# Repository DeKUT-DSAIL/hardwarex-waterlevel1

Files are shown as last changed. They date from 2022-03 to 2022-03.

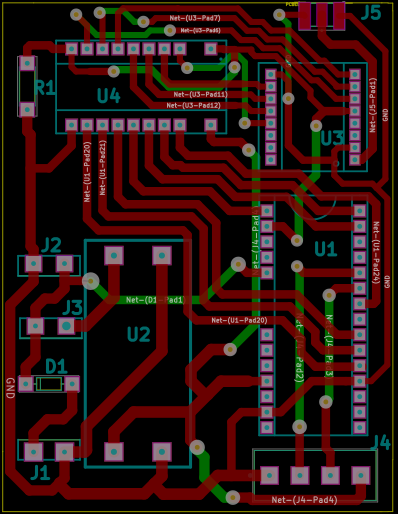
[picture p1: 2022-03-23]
arduino-waterlevel-hardware/design_pdfs/arduino_sytem-pcb.PNG

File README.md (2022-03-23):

## hardwarex-waterlevel1
### A Low Cost LoRa Based River Water Level Data Acquisition System (Design Files)
#### Contents
- Arduino Nano based stage monitoring system - Kicad design files (etching pdf available)
- Multitech mDot based stage monitoring system - Kicad design files (etching pdf available)
- Arduino Nano based stage monitoring system - Arduino IDE code (Firmware)
- TTN (The Things Network) payload formatter for the Multitech mDot based stage monitoring system (in JavaScript)

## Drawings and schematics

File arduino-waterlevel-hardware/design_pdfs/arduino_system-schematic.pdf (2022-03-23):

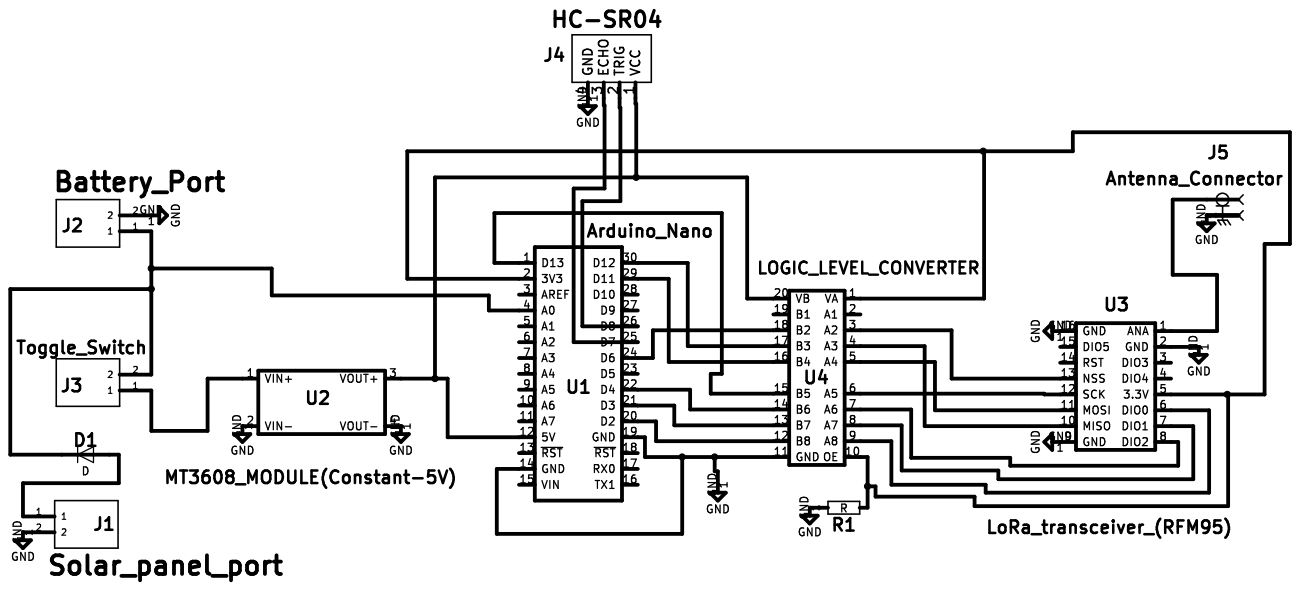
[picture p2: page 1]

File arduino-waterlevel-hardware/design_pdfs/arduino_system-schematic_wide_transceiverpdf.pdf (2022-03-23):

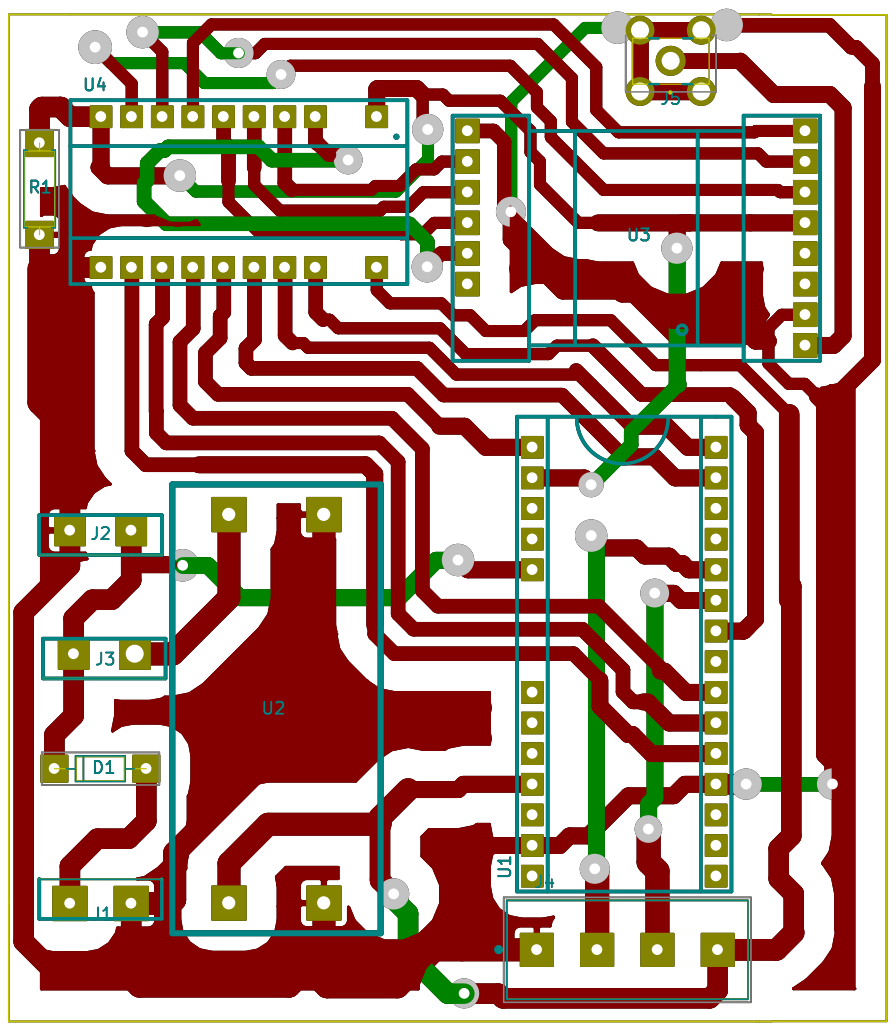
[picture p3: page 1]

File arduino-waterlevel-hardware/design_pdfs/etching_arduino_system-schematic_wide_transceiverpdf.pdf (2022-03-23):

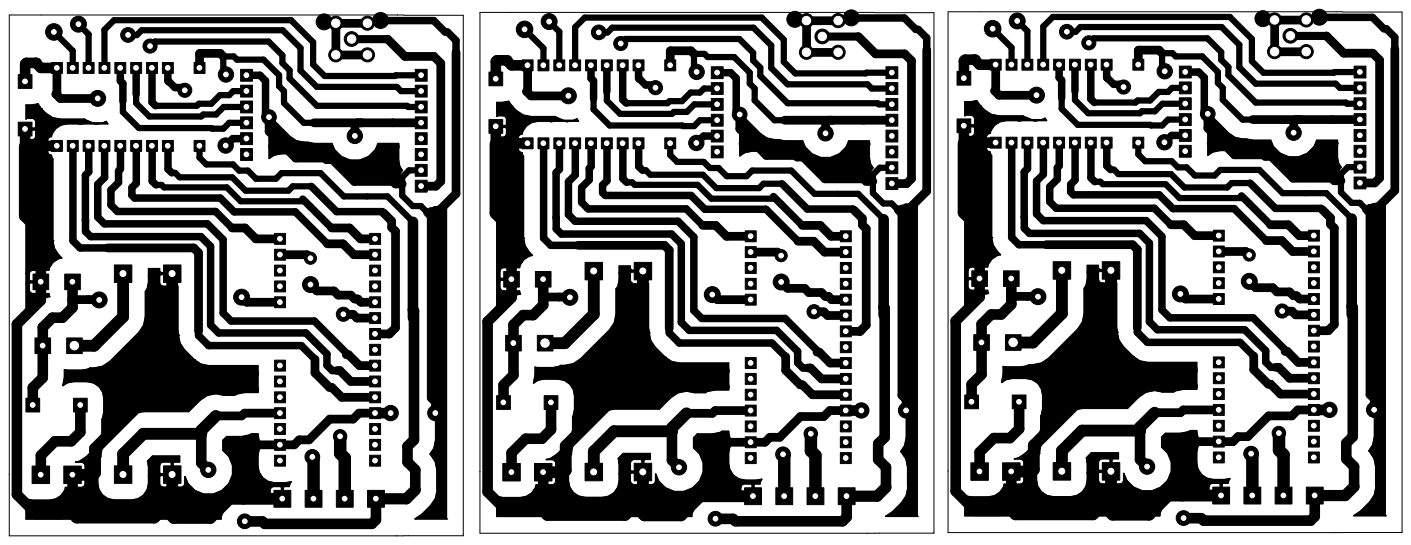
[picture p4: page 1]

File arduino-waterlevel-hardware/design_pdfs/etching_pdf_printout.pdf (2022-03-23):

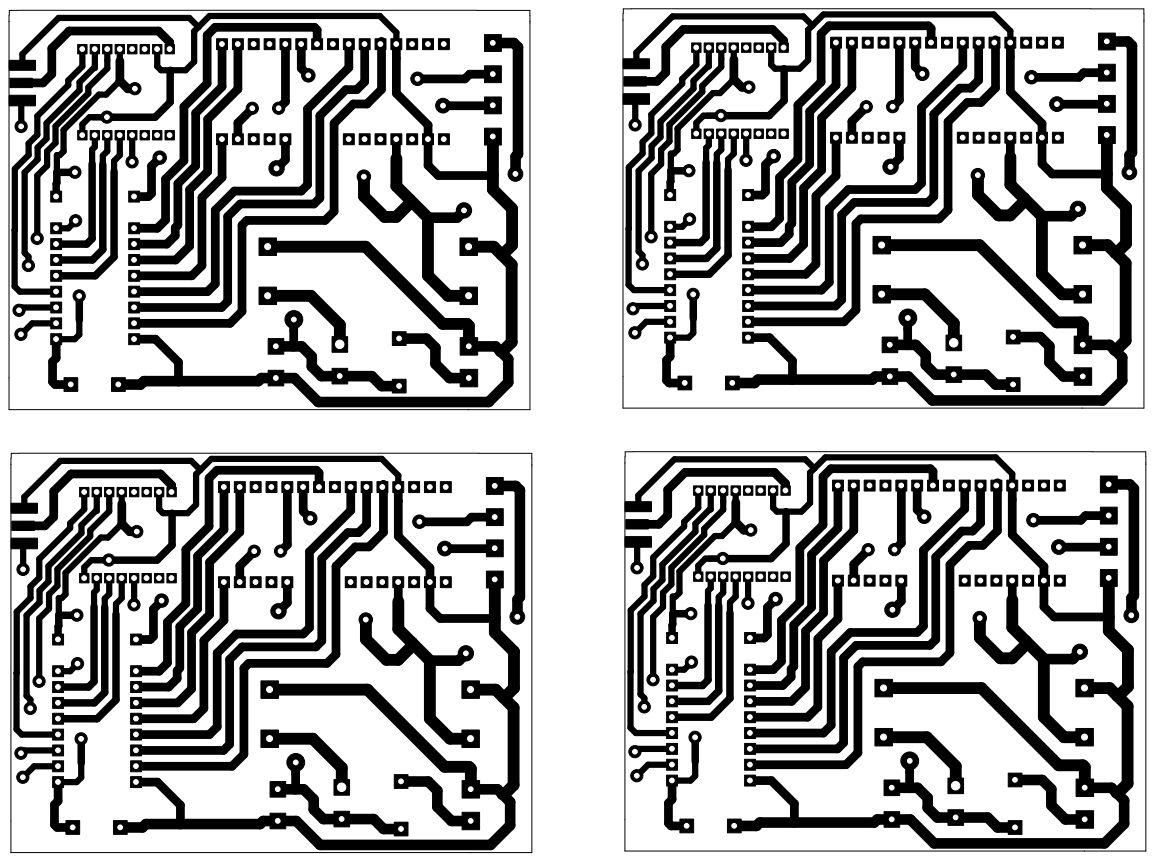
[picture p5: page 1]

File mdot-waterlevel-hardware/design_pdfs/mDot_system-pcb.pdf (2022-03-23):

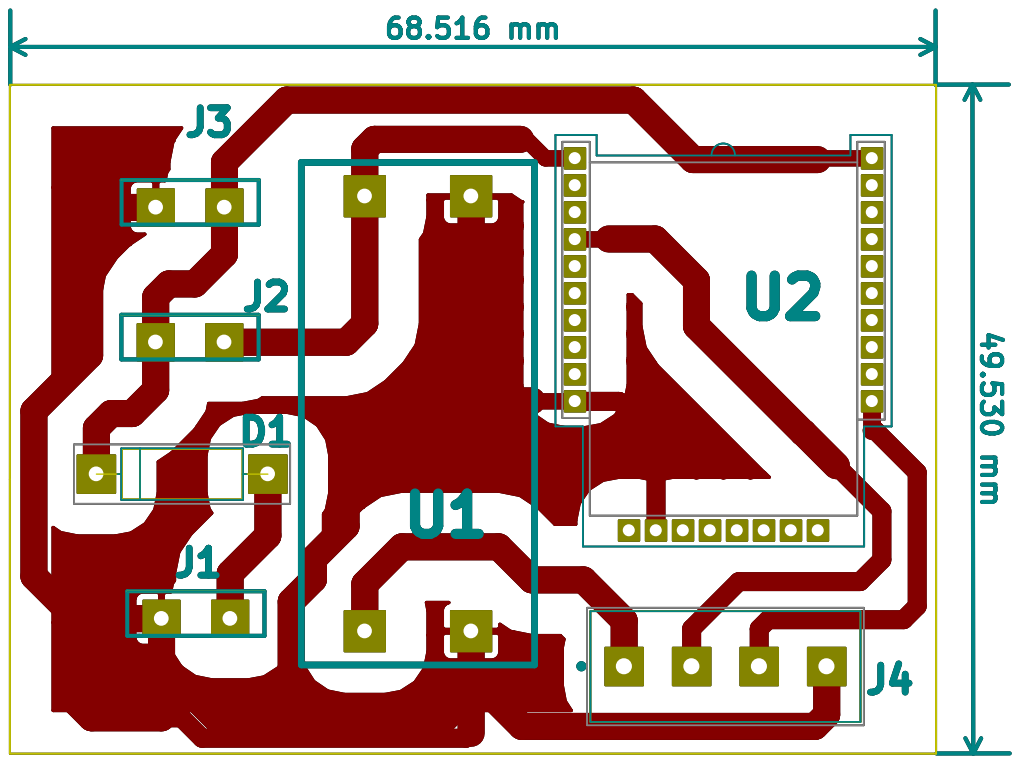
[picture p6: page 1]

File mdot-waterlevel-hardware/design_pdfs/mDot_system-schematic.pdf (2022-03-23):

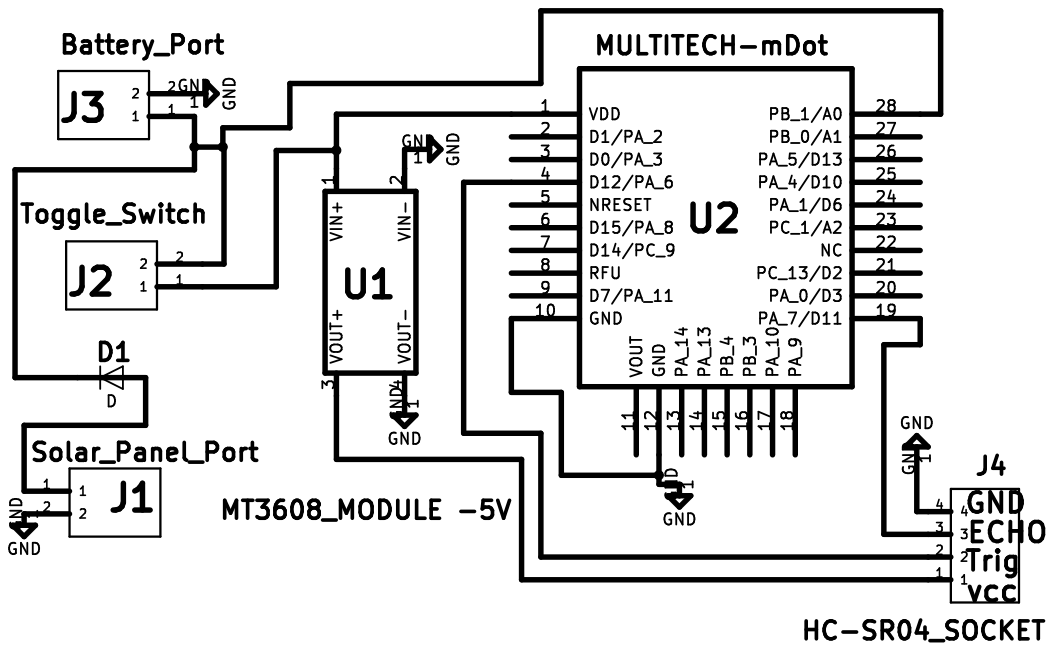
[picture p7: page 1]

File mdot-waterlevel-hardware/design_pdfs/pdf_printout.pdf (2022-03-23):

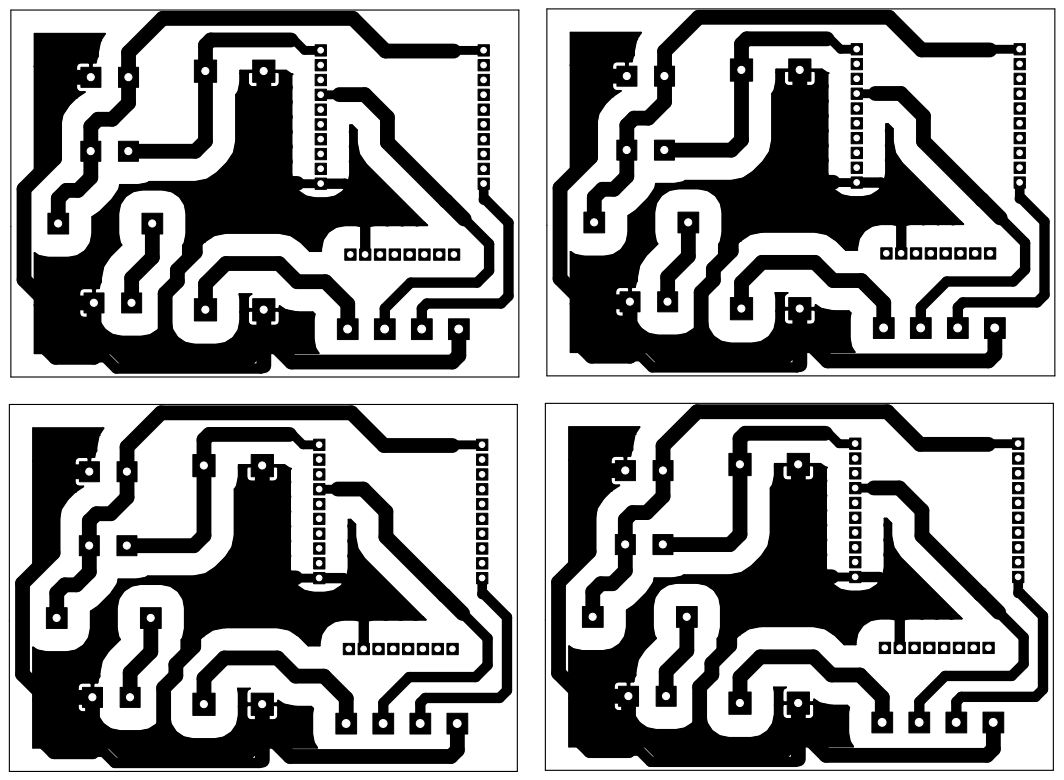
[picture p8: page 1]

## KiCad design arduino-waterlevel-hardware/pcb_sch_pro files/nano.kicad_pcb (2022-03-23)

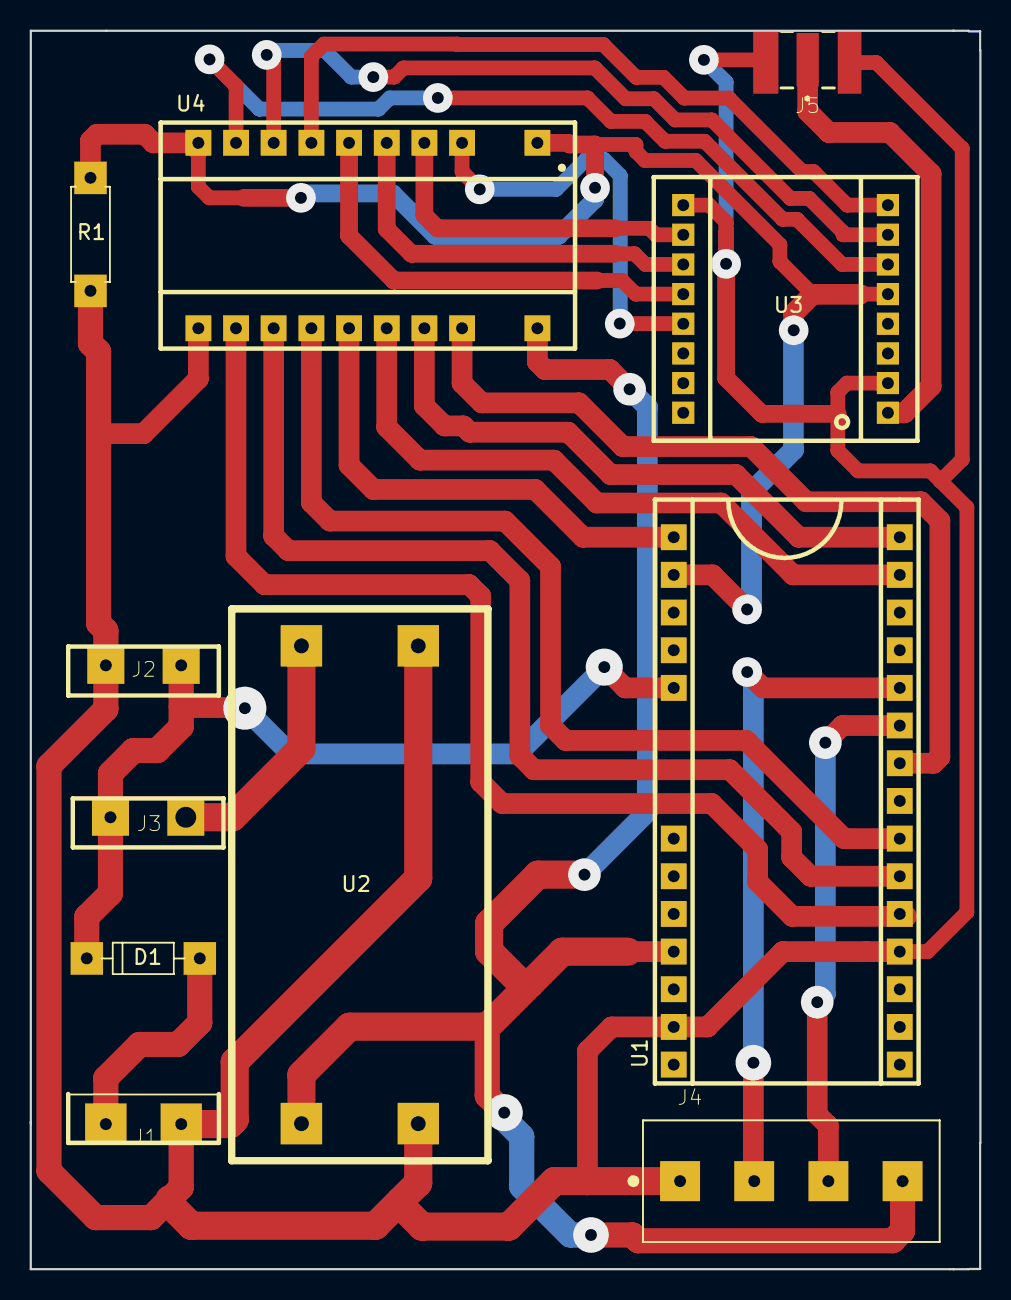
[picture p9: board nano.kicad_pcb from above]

Board: 2 copper layers, 64.0 x 83.5 mm, 11 parts (0 on the bottom side), 23 nets.

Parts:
D1: D_DO-35_SOD27_P7.62mm_Horizontal
J1, J2, J3: TE_282815-2
J4: TE_282836-4
J5: SAMTEC_SMA-J-P-H-ST-EM1
R1: R_Axial_DIN0207_L6.3mm_D2.5mm_P7.62mm_Horizontal
U1: nano
U2: MT3608
U3: brake1
U4: SHIFT

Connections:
GND: J1.1, J2.1, J4.1, J5.2_1, J5.2_2, J5.3_1, J5.3_2, R1.1, U1.14, U1.19, U2.2, U2.4, U3.2, U3.9, U4.11
unnamed: D1.1, J2.2, J3.1
unnamed: D1.2, J1.2
unnamed: J3.2, U2.1
unnamed: J4.2, U1.26
unnamed: J4.3, U1.25
unnamed: J4.4, U1.12, U2.3, U4.20
unnamed: J5.1, U3.1
unnamed: R1.2, U1.2, U3.5, U4.1, U4.10
unnamed: U1.1, U4.15
unnamed: U1.20, U4.12
unnamed: U1.21, U4.13
unnamed: U1.22, U4.14
unnamed: U1.24, U4.18
unnamed: U1.29, U4.16
unnamed: U1.30, U4.17
unnamed: U3.6, U4.9
unnamed: U3.7, U4.8
unnamed: U3.8, U4.7
unnamed: U3.10, U4.4
unnamed: U3.11, U4.5
unnamed: U3.12, U4.6
unnamed: U3.13, U4.3

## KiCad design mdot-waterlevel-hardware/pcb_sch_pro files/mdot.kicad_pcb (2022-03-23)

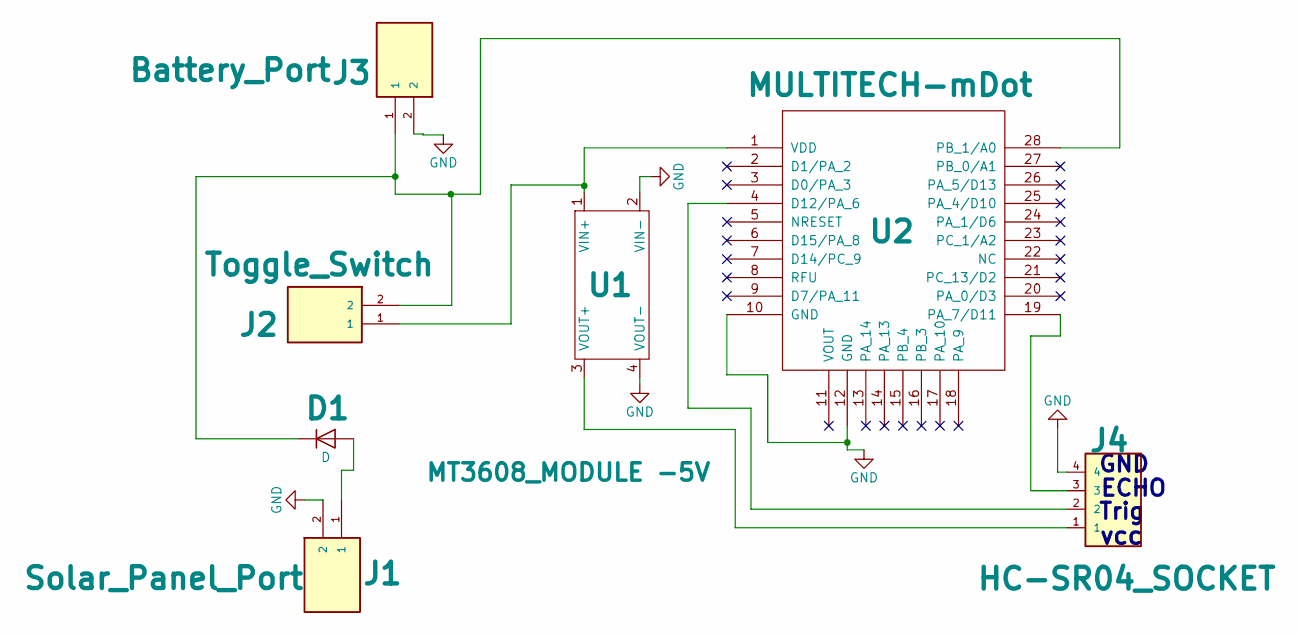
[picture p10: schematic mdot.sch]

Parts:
D1: D; D_5W_P12.70mm_Horizontal
J1: Solar_Panel_Port; TE_282815-2
J2: Toggle_Switch; TE_282815-2
J3: Battery_Port; TE_282815-2
J4: HC-SR04_SOCKET; TE_282836-4
U1: MT3608_MODULE -5V; MT3608
U2: MULTITECH-mDot; MDOT_TRIAL_BAT_CHARGER

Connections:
GND: J1.2, J3.2, J4.4, U1.2 (VIN-), U1.4 (VOUT-), U2.10 (GND), U2.12 (GND)
unnamed: D1.1 (K), J2.2, J3.1, U2.28 (PB_1/A0)
unnamed: D1.2 (A), J1.1
unnamed: J2.1, U1.1 (VIN+), U2.1 (VDD)
unnamed: J4.1, U1.3 (VOUT+)
unnamed: J4.2, U2.4 (D12/PA_6)
unnamed: J4.3, U2.19 (PA_7/D11)

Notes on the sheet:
vcc
Trig
ECHO
GND

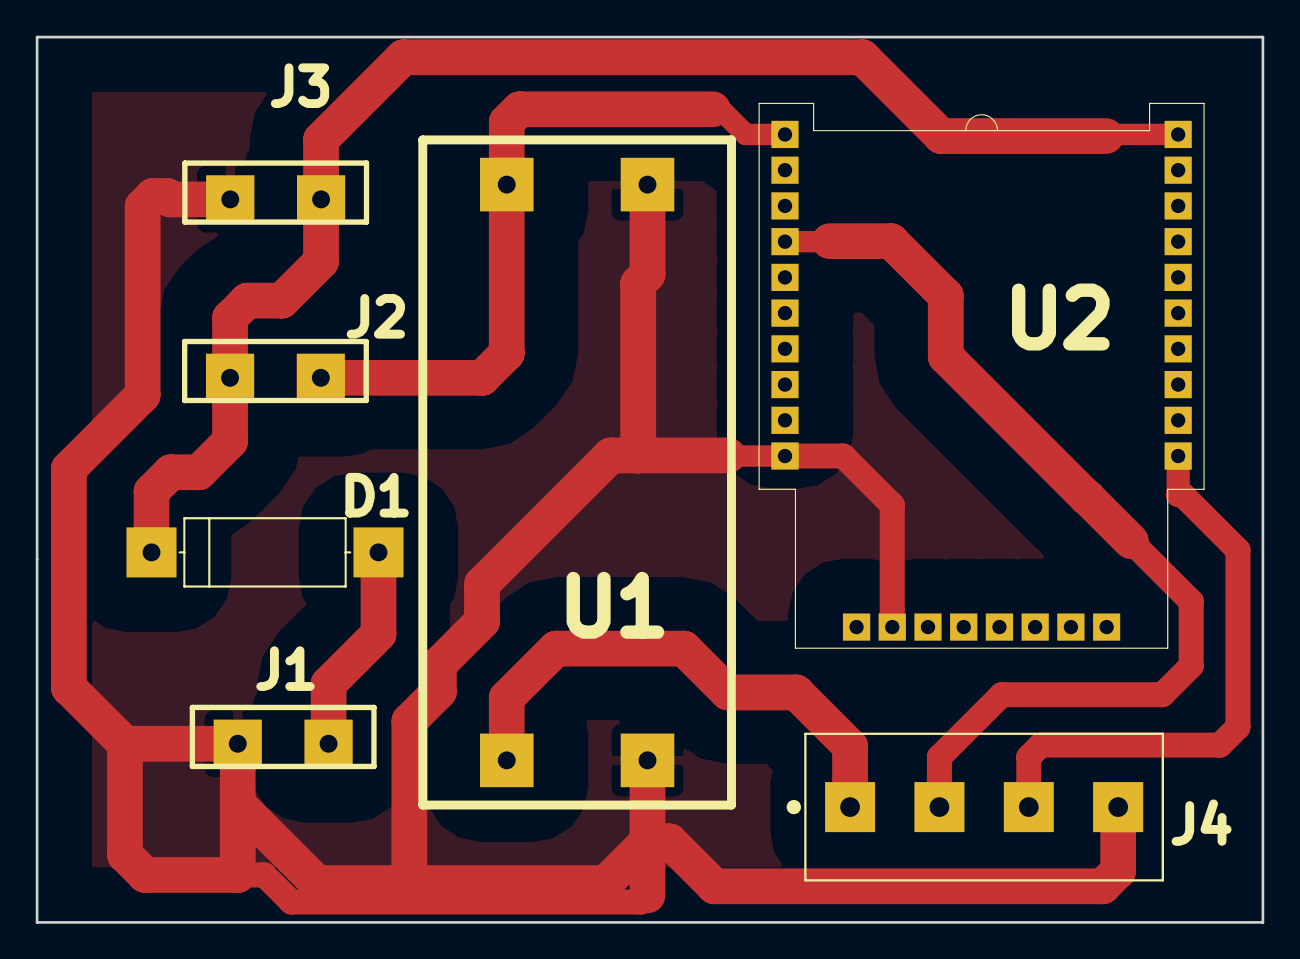
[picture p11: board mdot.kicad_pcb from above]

Board: 2 copper layers, 68.6 x 49.5 mm, 7 parts (0 on the bottom side), 7 nets.

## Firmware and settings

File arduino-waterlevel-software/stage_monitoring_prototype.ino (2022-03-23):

#include <lmic.h>        
#include <hal/hal.h>
#include <SPI.h>
#include <CayenneLPP.h>  



int trigger=7; 
int echo=8;  
int done=10;
int analogPin = A0;
CayenneLPP lpp(51);


// TTN DEVICE NETWORK SESSION KEY (msb)   
static const PROGMEM u1_t NWKSKEY[16] ={ 0x00, 0x00, 0x00, 0x00, 0x00, 0x00, 0x00, 0x00, 0x00, 0x00, 0x00, 0x00, 0x00, 0x00, 0x00, 0x00 };

//TTN DEVICE APPLICATION SESSION KEY (msb) 
static const u1_t PROGMEM APPSKEY[16] ={ 0x00, 0x00, 0x00, 0x00, 0x00, 0x00, 0x00, 0x00, 0x00, 0x00, 0x00, 0x00, 0x00, 0x00, 0x00, 0x00 };

// DEVICE ADDRESS ON TTN
static const u4_t DEVADDR = 0x12345678 ; // <-- Change this address for every node!

// These callbacks are only used in over-the-air activation, so they are left empty here 
void os_getArtEui (u1_t* buf) { }
void os_getDevEui (u1_t* buf) { }
void os_getDevKey (u1_t* buf) { }

static osjob_t sendjob;

// DATA intervals

const unsigned TX_INTERVAL = 60;

// Pin mapping for LoRa RFM95

const lmic_pinmap lmic_pins = {
    .nss = 6,
    .rxtx = LMIC_UNUSED_PIN,
    .rst = 5,
    .dio = {2, 3, 4},
};

void onEvent (ev_t ev) {
    Serial.print(os_getTime());
    Serial.print(": ");
    switch(ev) {
        case EV_SCAN_TIMEOUT:
            Serial.println(F("EV_SCAN_TIMEOUT"));
            break;
        case EV_BEACON_FOUND:
            Serial.println(F("EV_BEACON_FOUND"));
            break;
        case EV_BEACON_MISSED:
            Serial.println(F("EV_BEACON_MISSED"));
            break;
        case EV_BEACON_TRACKED:
            Serial.println(F("EV_BEACON_TRACKED"));
            break;
        case EV_JOINING:
            Serial.println(F("EV_JOINING"));
            break;
        case EV_JOINED:
            Serial.println(F("EV_JOINED"));
            break;
        case EV_RFU1:
            Serial.println(F("EV_RFU1"));
            break;
        case EV_JOIN_FAILED:
            Serial.println(F("EV_JOIN_FAILED"));
            break;
        case EV_REJOIN_FAILED:
            Serial.println(F("EV_REJOIN_FAILED"));
            break;
            break;
        case EV_TXCOMPLETE:
            Serial.println(F("EV_TXCOMPLETE (includes waiting for RX windows)"));
              digitalWrite(done, HIGH); 
             if (LMIC.txrxFlags & TXRX_ACK) {
          Serial.println(F("Received ack"));
         
        }
            if(LMIC.dataLen) {
                // data received in rx slot after tx
                Serial.print(F("Data Received: "));
                Serial.write(LMIC.frame+LMIC.dataBeg, LMIC.dataLen);
                Serial.println();
            }
            else
            {
               Serial.print(F("No Data Received :("));
              // Serial.print(LMIC.dataLen);
              }
            // Schedule next transmission
            os_setTimedCallback(&sendjob, os_getTime()+sec2osticks(TX_INTERVAL), do_send);
            break;
        case EV_LOST_TSYNC:
            Serial.println(F("EV_LOST_TSYNC"));
            break;
        case EV_RESET:
            Serial.println(F("EV_RESET"));
            break;
        case EV_RXCOMPLETE:
            // data received in ping slot
            Serial.println(F("EV_RXCOMPLETE"));
            break;
        case EV_LINK_DEAD:
            Serial.println(F("EV_LINK_DEAD"));
            break;
        case EV_LINK_ALIVE:
            Serial.println(F("EV_LINK_ALIVE"));
            break;
         default:
            Serial.println(F("Unknown event"));
            break;
    }
}

void do_send(osjob_t* j){
    // Check if there is not a current TX/RX job running
    if (LMIC.opmode & OP_TXRXPEND) {
        Serial.println(F("OP_TXRXPEND, not sending"));
    } else {

    lpp.reset();
    lpp.addAnalogInput(1,getdistance());
    lpp.addAnalogInput(2,getvoltage());
      // Prepare upstream data transmission at the next possible time.
    LMIC_setTxData2(1, lpp.getBuffer(), lpp.getSize(), 0);
    LMIC_setTxData2(2, lpp.getBuffer(), lpp.getSize(), 0);
 
       
        Serial.println(F("Packet queued"));
    }
    // Next TX is scheduled after TX_COMPLETE event.
}

void setup() {
    Serial.begin(115200);
    Serial.println(F("Starting"));


    pinMode(trigger, OUTPUT); 
    pinMode(done, OUTPUT);
    pinMode(echo, INPUT); 

    
    #ifdef VCC_ENABLE
    // For Pinoccio Scout boards
    pinMode(VCC_ENABLE, OUTPUT);
    digitalWrite(VCC_ENABLE, HIGH);
    delay(1000);
    #endif

    // LMIC init
    os_init();
    // Reset the MAC state. Session and pending data transfers will be discarded.
    LMIC_reset();
    LMIC_setClockError(MAX_CLOCK_ERROR * 1 / 100);
    // Set static session parameters. Instead of dynamically establishing a session
    // by joining the network, precomputed session parameters are be provided.
    #ifdef PROGMEM
    // On AVR, these values are stored in flash and only copied to RAM
    // once. Copy them to a temporary buffer here, LMIC_setSession will
    // copy them into a buffer of its own again.
    uint8_t appskey[sizeof(APPSKEY)];
    uint8_t nwkskey[sizeof(NWKSKEY)];
    memcpy_P(appskey, APPSKEY, sizeof(APPSKEY));
    memcpy_P(nwkskey, NWKSKEY, sizeof(NWKSKEY));
    LMIC_setSession (0x1, DEVADDR, nwkskey, appskey);
    #else
    // If not running an AVR with PROGMEM, just use the arrays directly 
    LMIC_setSession (0x1, DEVADDR, NWKSKEY, APPSKEY);
    #endif

    // Set up the channels used by the Things Network, which corresponds
    // to the defaults of most gateways. Without this, only three base
    // channels from the LoRaWAN specification are used, which certainly
    // works, so it is good for debugging, but can overload those
    // frequencies, so be sure to configure the full frequency range of
    // your network here (unless your network autoconfigures them).
    // Setting up channels should happen after LMIC_setSession, as that
    // configures the minimal channel set.
    LMIC_setupChannel(0, 868100000, DR_RANGE_MAP(DR_SF12, DR_SF7),  BAND_CENTI);      // g-band
 //  LMIC_setupChannel(1, 868300000, DR_RANGE_MAP(DR_SF12, DR_SF7B), BAND_CENTI);      // g-band
//    LMIC_setupChannel(2, 868500000, DR_RANGE_MAP(DR_SF12, DR_SF7),  BAND_CENTI);      // g-band
//    LMIC_setupChannel(3, 867100000, DR_RANGE_MAP(DR_SF12, DR_SF7),  BAND_CENTI);      // g-band
//    LMIC_setupChannel(4, 867300000, DR_RANGE_MAP(DR_SF12, DR_SF7),  BAND_CENTI);      // g-band
//    LMIC_setupChannel(5, 867500000, DR_RANGE_MAP(DR_SF12, DR_SF7),  BAND_CENTI);      // g-band
 //  LMIC_setupChannel(6, 867700000, DR_RANGE_MAP(DR_SF12, DR_SF7),  BAND_CENTI);      // g-band
 //   LMIC_setupChannel(7, 867900000, DR_RANGE_MAP(DR_SF12, DR_SF7),  BAND_CENTI);      // g-band
 //  LMIC_setupChannel(8, 868800000, DR_RANGE_MAP(DR_FSK,  DR_FSK),  BAND_MILLI);      // g2-band
    // TTN defines an additional channel at 869.525Mhz using SF9 for class B
    // devices' ping slots. LMIC does not have an easy way to define set this
    // frequency and support for class B is spotty and untested, so this
    // frequency is not configured here.

    // Disable link check validation
    LMIC_setLinkCheckMode(0);

     // TTN uses SF9 for its RX2 window.
    LMIC.dn2Dr = DR_SF9;
 
    LMIC_disableChannel(1);    //disable channel 1 
    LMIC_disableChannel(2);  // disable channel 2 
 
    // Set data rate and transmit power (note: txpow seems to be ignored by the library)
    LMIC_setDrTxpow(DR_SF7,14);
  
    // Start job
    do_send(&sendjob);
}

void loop() {
    os_runloop_once();
    getdistance();
    getvoltage();
    
}

uint8_t getdistance(){
  long duration=0; 
  uint8_t distance=0; 
  digitalWrite(trigger, LOW); 
  delay(5); 
  digitalWrite(trigger, HIGH); 
  delay(10);
  digitalWrite(trigger, LOW);
  duration = pulseIn(echo, HIGH); 
  distance = (duration/2) * 0.03432; 
  return distance;
}

float getvoltage(){
  float voltage = 0;
  float v_conv;
  float v_conv2;
  voltage = analogRead(analogPin);
  //v_conv = (voltage/1023)* 5;
  v_conv = voltage/100;
  v_conv2 = v_conv/2; 
  return v_conv2;
  }
